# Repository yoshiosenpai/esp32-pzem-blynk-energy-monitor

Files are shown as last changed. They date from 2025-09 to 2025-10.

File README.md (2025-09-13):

# ESP32 + PZEM-004T v3.0 Energy Monitor with Blynk

Monitor **Voltage, Current, and Power** from a **PZEM-004T v3.0** and control **two AC bulbs** via relays, with live dashboards in **Blynk (Web & Mobile)**.

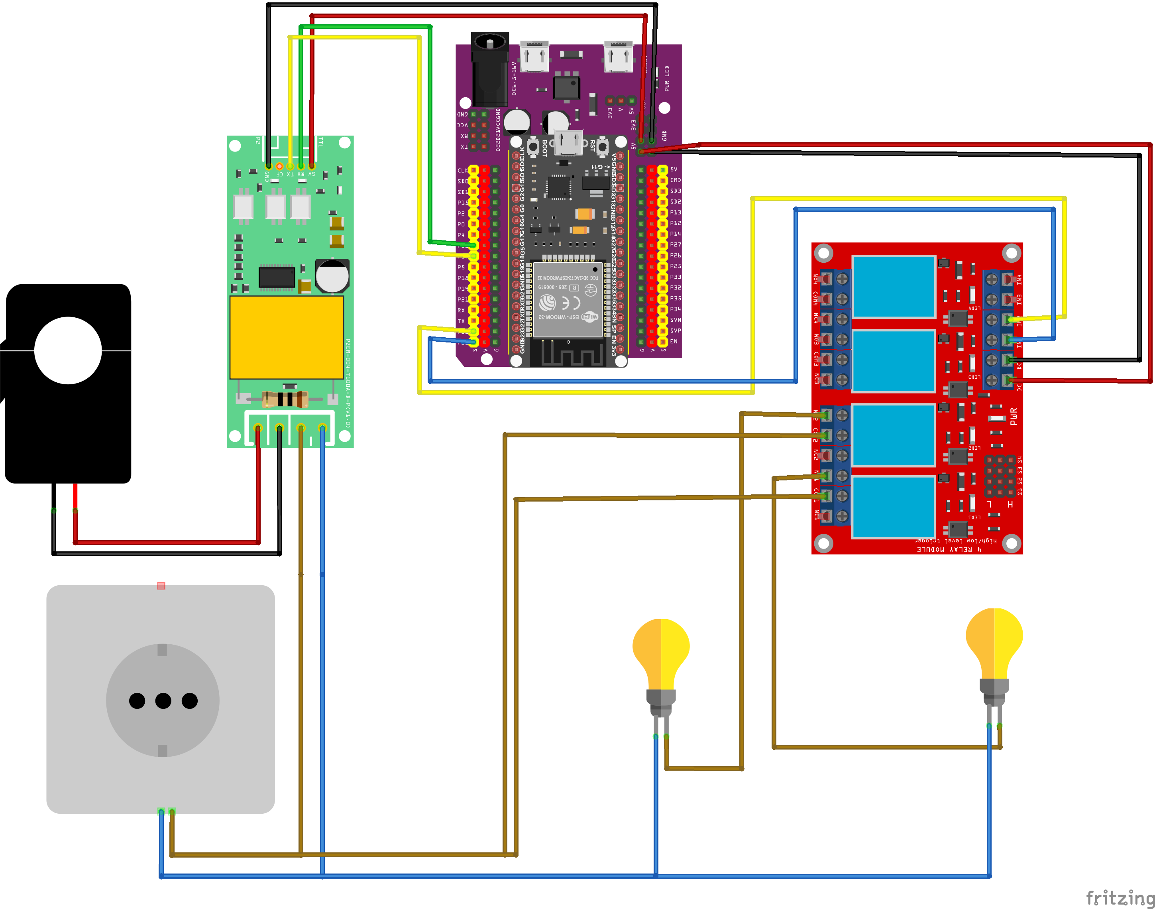
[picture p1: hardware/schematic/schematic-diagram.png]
Wiring Overview


---

## ✨ Features

* ESP32 + PZEM-004T v3.0 → real-time V/I/P/E readings
* Sends data to **Blynk Cloud** (Web & App dashboards)
* Control up to **2 relays** (bulbs, small appliances) from anywhere
* Safe wiring with CT clamp for current sensing
* Beginner-friendly: Arduino IDE only (no PlatformIO needed)

---

## 🛠 Hardware

* ESP32 Dev Board
* PZEM-004T v3.0 (with CT clamp)
* 2-Channel relay module (5V, active-LOW)
* 2 × AC bulbs + holders
* 3-pin fused plug (3A) + wiring accessories

---

## 🚀 Quickstart

1. Install **Arduino IDE** + **ESP32 board support**
2. Install libraries: `Blynk`, `PZEM004Tv30`
3. Clone this repo:

   ```bash
   git clone https://github.com/yoshiosenpai/esp32-pzem-blynk-energy-monitor.git
   ```
4. Copy `firmware/esp32_pzem_blynk/config.example.h` → `config.h` and add WiFi + Blynk token
5. Open `esp32_pzem_blynk.ino` → Select **ESP32 Dev Module** → Upload
6. Wire according to [docs/wiring-table.md](docs/wiring-table.md)
7. Open Serial Monitor → readings every \~2s
8. Open **Blynk Dashboard** → Voltage, Current, Power, Energy live + Relay switches

---

## ⚠️ Safety

This project involves **230 VAC mains**.

* Always use a **3 A fused plug**
* Keep wiring insulated and inside an enclosure
* Test with **low-wattage LED bulbs first**
* Not for heavy appliance loads

---

## 📂 Docs

* [Quickstart](docs/quickstart.md)
* [Wiring Table](docs/wiring-table.md)
* [Blynk Setup](docs/blynk-setup.md)

---

## 📜 License

MIT License – see [LICENSE](LICENSE).

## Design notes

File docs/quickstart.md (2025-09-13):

# Quickstart Guide

*ESP32 + PZEM-004T v3.0 + Blynk + Relay Energy Monitor*

---

## 1. Hardware

* ESP32 Dev Board (e.g. ESP32-DEVKIT V1)
* PZEM-004T v3.0 (AC energy monitor with CT clamp)
* 4-Channel relay module (5V, active-LOW)
* 2 × AC bulb + bulb holders (blue-stripe = Live, white = Neutral)
* CT clamp (red/black leads → S1/S2 on PZEM)
* 3-pin plug top with 3A fuse
* Breadboard / jumper wires / insulated enclosure

⚠️ **Warning:** This project uses 230 VAC mains. Always insulate, use a fused plug, and test with low-wattage LED bulbs first.

---

## 2. Arduino IDE Setup

1. Install [Arduino IDE](https://www.arduino.cc/en/software).
2. Install the **ESP32 board core**:

   * In IDE: `File → Preferences → Additional Board URLs`
   * Add:

     ```
     https://espressif.github.io/arduino-esp32/package_esp32_index.json
     ```
   * Then `Tools → Board → Boards Manager` → search **ESP32 by Espressif** → Install.
3. Install required libraries (`Tools → Manage Libraries`):

   * **Blynk** (by Volodymyr Shymanskyy)
   * **PZEM004Tv30** (by Jakub Mandula)

---

## 3. Clone the Repository

```bash
git clone https://github.com/yoshiosenpai/esp32-pzem-blynk-energy-monitor.git
cd esp32-pzem-blynk-energy-monitor/firmware/main.ino
```

---

## 4. Configure Firmware

1. Copy the example config:

   ```bash
   cp config.example.h config.h
   ```
2. Open `config.h` and edit:

   ```cpp
   #define BLYNK_TEMPLATE_ID   "YOUR_TEMPLATE_ID"
   #define BLYNK_TEMPLATE_NAME "YOUR_TEMPLATE_NAME"
   #define BLYNK_AUTH_TOKEN    "YOUR_BLYNK_AUTH_TOKEN"

   static char WIFI_SSID[] = "YOUR_WIFI";
   static char WIFI_PASS[] = "YOUR_PASSWORD";
   ```
3. In Arduino IDE: open `main.ino`.

---

## 5. Flash the ESP32

1. Select board: `Tools → Board → ESP32 Dev Module`.
2. Select correct COM port.
3. Click **Upload**.
4. Open Serial Monitor (115200 baud) → you should see live readings like:

   ```
   V=243.1 V | I=0.042 A | P=9.9 W |
   ```

---

## 6. Wiring Overview

* **Low voltage (ESP32 side):**

  * ESP32 5V → Relay VCC, PZEM VCC
  * ESP32 GND → Relay GND, PZEM GND
  * ESP32 GPIO16 (RX2) ← PZEM TX
  * ESP32 GPIO17 (TX2) → PZEM RX
  * ESP32 GPIO23 → Relay IN1
  * ESP32 GPIO22 → Relay IN2

* **High voltage (AC side):**

  * Plug **Live (L)** → PZEM L + Relay COM (both)
  * Relay NO Ch1 → Bulb1 blue-stripe (Live)
  * Relay NO Ch2 → Bulb2 blue-stripe (Live)
  * Plug **Neutral (N)** → PZEM N + Bulb1 & Bulb2 white (Neutral)

* **CT Clamp:**

  * Red → PZEM S1, Black → PZEM S2
  * Clamp around **one single Live wire** feeding the bulbs (NOT both L+N).

👉 Full wiring tables are in [`docs/wiring-table.md`](wiring-table.md).

---

## 7. Blynk Setup

1. In [Blynk Cloud](https://blynk.cloud): create a **Template → EnergyMonitor**.
2. Add Datastreams:

   * **V0** = Voltage (V)
   * **V1** = Current (A)
   * **V2** = Power (W)
   * **V10** = Relay 1 (Button)
   * **V11** = Relay 2 (Button)
3. Add Widgets:

   * Gauges / Value Displays for V0–V3
   * Switches for V10 & V11
4. Copy the **Template ID, Name, Auth Token** into `config.h`.

---

## 8. First Test

* Power on the ESP32 via USB.
* Power on the plug (with fuse) to supply the bulbs + PZEM.
* Open Serial Monitor → check Voltage ≈ 230–250 V.
* In Blynk dashboard → see V/I/P/E update every 2 s.
* Press Relay1 / Relay2 buttons → bulbs switch ON/OFF.

---

## 9. Troubleshooting

* **All values -1.0** → swap TX/RX, check 5V/GND.
* **Voltage OK, Current 0.000** → CT clamp on wrong wire / not tight / bulb OFF.
* **MCB trips immediately** → Neutral was put through relay; fix so only Live goes COM→NO.
* **ESP32 boot error (invalid header)** → unplug peripherals, erase & flash Blink, then reconnect.

---

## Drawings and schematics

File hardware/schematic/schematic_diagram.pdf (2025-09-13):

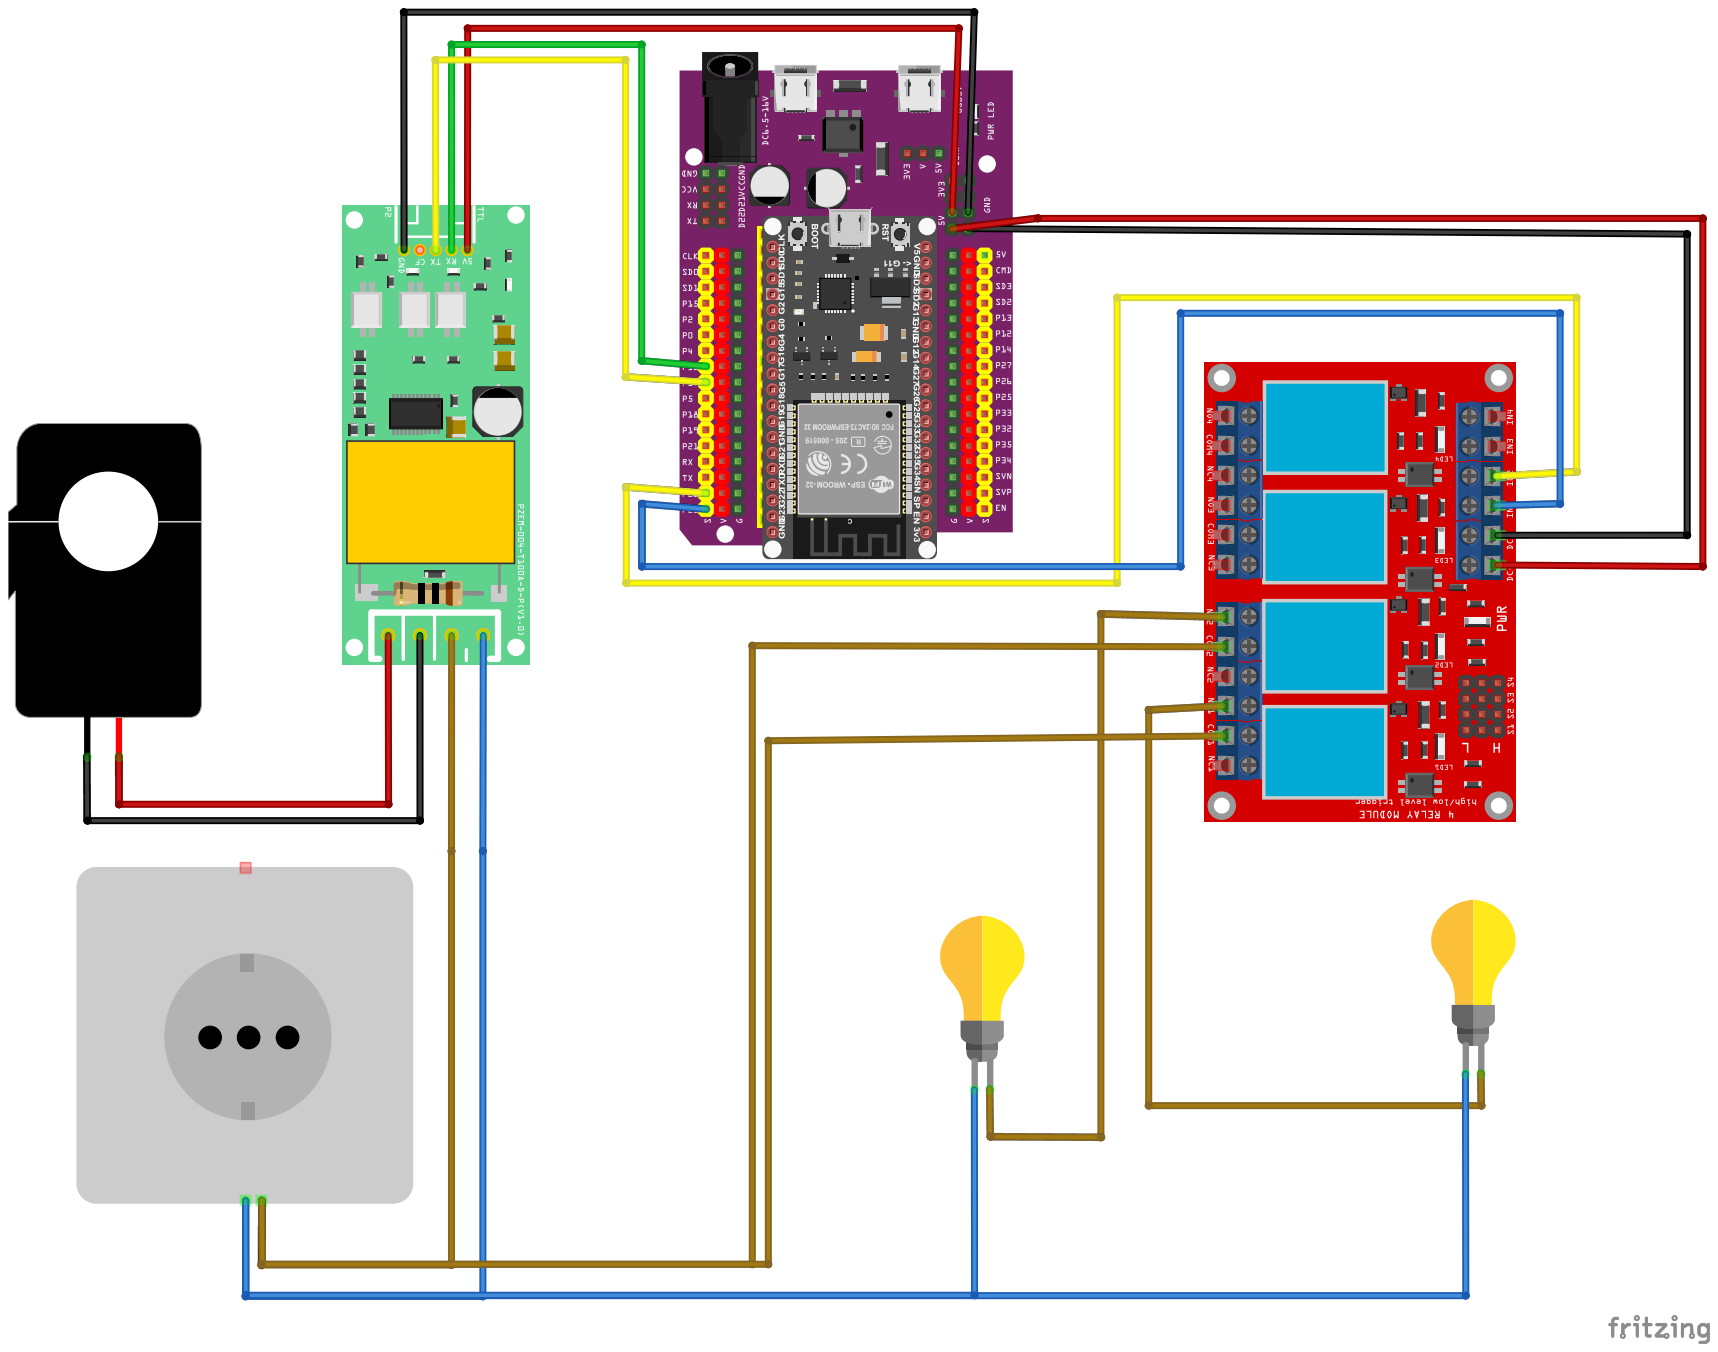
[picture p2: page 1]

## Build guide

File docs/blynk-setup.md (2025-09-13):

# Blynk Setup (Template, Datastreams, Dashboard)
> You only need to do this once per Template. After that, any device using this firmware can be provisioned in seconds.

---

## 1) Create a Blynk Template

1. Go to **[blynk.cloud](https://blynk.cloud)** → log in.
2. **Developer Zone → Templates → New Template**

   * **Template Name:** `EnergyMonitor`
   * **Hardware:** `ESP32`
   * **Connection Type:** `WiFi`
3. Click **Create**.

### Copy Template IDs

Open **Template → Device Info** and copy:

* `BLYNK_TEMPLATE_ID`
* `BLYNK_TEMPLATE_NAME`
* (We’ll get the device’s **Auth Token** after adding a device.)

Paste these into your firmware’s `config.h` later.

---

## 2) Add Datastreams (Virtual Pins)

Inside **EnergyMonitor → Datastreams → Add Datastream → Virtual Pin**
Create the following:

### Sensor values

| Name | Virtual Pin | Data Type | Units | Min | Max  | Recommended Widget |
| --- | --- | --- | ----- | --- | ---- | --- |
| Voltage | **V0** | Double | V | 0 | 260  | Value Display / Gauge |
| Current | **V1** | Double | A | 0 | 10 | Value Display / Gauge |
| Power | **V2** | Double | W | 0 | 2500 | Value Display / Gauge |
| Energy  | **V3** | Double | kWh | 0 | 9999 | Value Display |

> The firmware pushes fresh values every \~2 s.

### Relay controls

| Name | Virtual Pin | Data Type | Min | Max | Recommended Widget |
| --- | --- | --- | --- | --- | --- |
| Relay 1 | **V10** | Integer | 0 | 1 | Switch / Button |
| Relay 2 | **V11** | Integer | 0 | 1 | Switch / Button |

> 0 = OFF, 1 = ON. Most 5V relay boards are **active-LOW**; the firmware handles this for you.

*(Optional extras if you add them in code later)*

| Name | Virtual Pin | Data Type | Units | Min | Max |
| --- | --- | --- | ----- | --- | --- |
| Frequency | V4 | Double | Hz | 45  | 65  |
| PowerFactor | V5 | Double | — | 0 | 1 |

---

## 3) Create the Web Dashboard

1. In the template, open **Web Dashboard**.
2. Add widgets and map them to the datastreams:

**Recommended layout**

* **Value Display** → Voltage (V0)
* **Value Display** → Current (V1)
* **Value Display** → Power (V2)
* **Switch** → Relay 1 (V10)
* **Switch** → Relay 2 (V11)

**Widget tips**

* For Voltage/Current/Power: set **Decimals** (Voltage: 1; Current: 3; Power: 1)
* For Energy (kWh): set **Decimals: 3** (or 2)
* Title each widget clearly (e.g., “Voltage (V)”)

Click **Save** (top-right).

---

## 4) Create the Mobile Dashboard (optional)

In the **Blynk mobile app** (iOS/Android):

1. Log in with the same account.
2. Add your device (after provisioning below).
3. Add widgets and map the same pins:

   * Value Displays for **V0–V3**
   * Switches for **V10, V11**
4. Save.

---

## 5) Provision a Device (get the Auth Token)

1. Go to **My Devices → New Device → From Template**
2. Choose **EnergyMonitor**
3. Name your device (e.g., “Lab Energy Monitor”)
4. After creation, open the device → **Device Info** → copy the **Auth Token**.

Paste this **Auth Token** into your `config.h`:

```cpp
#define BLYNK_TEMPLATE_ID   "YOUR_TEMPLATE_ID"
#define BLYNK_TEMPLATE_NAME "EnergyMonitor"
#define BLYNK_AUTH_TOKEN    "PASTE_DEVICE_TOKEN_HERE"
```

Also set your Wi-Fi:

```cpp
static char WIFI_SSID[] = "YOUR_WIFI";
static char WIFI_PASS[] = "YOUR_PASSWORD";
```

Rebuild & upload the firmware.

---

## 6) Verify Data Flow

* Open **Serial Monitor (115200)** → you should see lines like:

  ```
  V=243.1 V | I=0.042 A | P=9.9 W | E=0.002 kWh
  ```
* Open your **Blynk Web Dashboard** → V0..V3 updating every \~2s.
* Use **Relay 1 / Relay 2** switches → bulbs should toggle.

If values don’t show, see Troubleshooting below.

---

## 7) Expected Ranges

* **Voltage (V0):** 200–260 V (MY mains typically \~230–245 V)
* **Current (V1):** 0.00–0.10 A for 9W LED (≈ 0.04 A typical)
* **Power (V2):** 0–200 W (≈ 7–10 W for one LED bulb)

---

## 8) Troubleshooting (Blynk side)

* **No values on dashboard, but device is online**

  * Check that each widget is mapped to the correct **Virtual Pin** (V0..V3).
  * Ensure datastream **Data Type** matches firmware (Double for sensors).
  * Confirm the device’s **Auth Token** in `config.h` matches the device in Blynk.

* **Device offline**

  * Wrong Wi-Fi SSID/PASS or token. Test with a phone hotspot.
  * Re-upload after fixing `config.h`.

* **Values frozen**

  * Check Serial Monitor for sensor errors. If firmware can’t read PZEM, it won’t push updates.
  * Make sure you **saved** the Web Dashboard after editing.

> For wiring/firmware issues (e.g., V reads OK but I=0), see `docs/troubleshooting.md`.

---

## 9) Security & Best Practices

* Don’t commit `config.h` (contains tokens/passwords). The repo ignores it via `.gitignore`.
* Use a separate **device** in Blynk for each physical ESP32.
* For public demos, regenerate Auth Tokens after.

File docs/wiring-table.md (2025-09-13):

# Wiring Table – ESP32 + PZEM-004T v3.0 + Relay + 2 Bulbs

⚠️ **Safety First**: This project involves 230 VAC. Use a fused plug (3 A), insulated terminals/enclosure, and never touch AC wiring while powered.

---

## 🔹 Low-Voltage Wiring (ESP32 → PZEM & Relay)

| From (Device) | Pin/Terminal | To (Device)  | Pin/Terminal | Notes |
| --- | --- | --- | --- | --- |
| ESP32 | 5V | PZEM-004T | VCC | Powers PZEM logic |
| ESP32 | GND | PZEM-004T | GND | Common ground |
| ESP32 (GPIO16 RX2) | RX2 | PZEM-004T | TX | Receive from PZEM |
| ESP32 (GPIO17 TX2) | TX2 | PZEM-004T | RX | Send to PZEM |
| ESP32 | 5V | Relay module | VCC | Powers relay board |
| ESP32 | GND | Relay module | GND | Common ground |
| ESP32 (GPIO23) | Digital Pin  | Relay module | IN1 | Control Relay 1 (Bulb 1) |
| ESP32 (GPIO22) | Digital Pin  | Relay module | IN2 | Control Relay 2 (Bulb 2) |

---

## 🔹 High-Voltage Wiring (AC Plug → PZEM → Relay → Bulbs)

### Common Connections

| From (Device) | Pin/Terminal | To (Device) | Pin/Terminal | Notes |
| --- | --- | --- | --- | --- |
| 3-Pin Plug | Live (L, brown) | PZEM-004T | AC-IN L | Supplies PZEM and feeds relays |
| 3-Pin Plug | Neutral (N, blue) | PZEM-004T | AC-IN N | Supplies PZEM and bulbs |
| 3-Pin Plug | Neutral (N, blue) | Bulb 1 Holder | White wire | Neutral direct to Bulb 1 |
| 3-Pin Plug | Neutral (N, blue) | Bulb 2 Holder | White wire | Neutral direct to Bulb 2 |

---

### Bulb 1 (Relay Channel 1)

| From (Device) | Pin/Terminal | To (Device) | Pin/Terminal | Notes |
| --- | --- | --- | --- | --- |
| 3-Pin Plug Live | — | Relay Ch1 | COM | Live input |
| Relay Ch1 | NO | Bulb 1 Holder | Blue-stripe (Live) | Switched Live to Bulb 1 |

---

### Bulb 2 (Relay Channel 2)

| From (Device) | Pin/Terminal | To (Device) | Pin/Terminal | Notes |
| --- | --- | --- | --- | --- |
| 3-Pin Plug Live | — | Relay Ch2 | COM | Live input |
| Relay Ch2 | NO | Bulb 2 Holder | Blue-stripe (Live) | Switched Live to Bulb 2 |

---

## 🔹 CT Clamp Wiring

| From (Device) | Pin/Lead | To (Device) | Pin/Terminal | Notes |
| --- | --- | --- | --- | --- |
| CT Clamp | Red lead | PZEM-004T | S1 | CT input |
| CT Clamp | Black lead | PZEM-004T | S2 | CT input |

* Clamp must be **around one single Live wire only** (e.g. the wire between Relay NO → Bulb Live).
* Do **not** clamp both Live + Neutral, or the reading will always be 0 A.
* If power shows negative, flip clamp orientation.

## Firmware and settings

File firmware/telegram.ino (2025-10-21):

/****************************************************
 * ESP32 + PZEM-004T v3.0 + Blynk (UNCHANGED UX)
 * + Telegram (group-ready): /status, /on1, /off1, /on2, /off2, /on, /off
 * + Night alerts per lamp (22:00–07:00 MYT) + "unknown load" alert
 * Notes:
 * - Set BotFather Group Privacy = OFF (recommended)
 * - TELEGRAM_CHAT_ID must match your group's negative ID exactly
 ****************************************************/

// ---- Blynk (unchanged) ----
#define BLYNK_TEMPLATE_ID   "BLYNK TEMPLATE ID"
#define BLYNK_TEMPLATE_NAME "BLYNK TEMPLATE NAME"
#define BLYNK_AUTH_TOKEN    "BLYNK TOKEN"

#include <Arduino.h>
#include <WiFi.h>
#include <WiFiClientSecure.h>
#include <HTTPClient.h>
#include <BlynkSimpleEsp32.h>
#include <PZEM004Tv30.h>
#include <time.h>

// ---- Wi-Fi ----
char ssid[] = "WIFI NAME";
char pass[] = "WIFI PASSWORD";

// ---- Telegram ----
// Group chat IDs are negative (e.g. "-1001234567890")
#define TELEGRAM_BOT_TOKEN "XXXXXXXX:YYYYYYYYYYYYYYYYYYYYYYYYYYYYYYY"
#define TELEGRAM_CHAT_ID   "-1001234567890"

// ---- Pins (unchanged) ----
#define RX_PIN   16   // ESP32 RX2  <- PZEM TX
#define TX_PIN   17   // ESP32 TX2  -> PZEM RX
#define RELAY1   23   // Blynk V10 (Lamp 1)
#define RELAY2   22   // Blynk V11 (Lamp 2)

const bool RELAY_ACTIVE = LOW;
const bool RELAY_IDLE   = HIGH;

// ---- Objects ----
HardwareSerial PZEMSerial(2);
PZEM004Tv30 pzem(PZEMSerial, RX_PIN, TX_PIN);
BlynkTimer timer;

// ---- Blynk handlers (unchanged) ----
BLYNK_WRITE(V10) { digitalWrite(RELAY1, param.asInt() ? RELAY_ACTIVE : RELAY_IDLE); }
BLYNK_WRITE(V11) { digitalWrite(RELAY2, param.asInt() ? RELAY_ACTIVE : RELAY_IDLE); }

// ---- Night alert settings ----
const uint8_t NIGHT_START_H = 22;   // 22:00
const uint8_t NIGHT_END_H   = 7;    // 07:00
unsigned long NIGHT_ON_MINUTES = 5; // minutes ON before alert
const unsigned long NOTIF_COOLDOWN_MS = 30UL * 60UL * 1000UL; // 30min cooldown

// Power threshold for "unknown load" (when both relays OFF)
float ON_W_THRESHOLD = 5.0; // W

// ---- State per lamp ----
struct LampState {
  uint8_t pin;
  const char* name;
  unsigned long onSinceMs = 0;
  unsigned long lastNotifMs = 0;
};
LampState lamps[2] = {
  { RELAY1, "Lamp 1" },
  { RELAY2, "Lamp 2" }
};

// Unknown load state (relays OFF but power high)
unsigned long unknownOnSinceMs = 0;
unsigned long unknownLastNotifMs = 0;

// Telegram polling
long telegramUpdateOffset = 0;

// ---- NTP Time (Asia/Kuala_Lumpur) ----
const long GMT_OFFSET_SEC = 8 * 3600;
const int  DST_OFFSET_SEC = 0;

static inline bool relayIsOn(uint8_t pin) { return digitalRead(pin) == RELAY_ACTIVE; }

bool getLocalHour(uint8_t &hourOut) {
  struct tm t;
  if (!getLocalTime(&t, 1000)) return false;
  hourOut = (uint8_t)t.tm_hour;
  return true;
}
bool inNightWindow(uint8_t hr) {
  // 22→07 wraps midnight
  if (NIGHT_START_H < NIGHT_END_H) return (hr >= NIGHT_START_H && hr < NIGHT_END_H);
  return (hr >= NIGHT_START_H || hr < NIGHT_END_H);
}

// ---------- Telegram helpers & normalization ----------
String normalizeCmd(String s) {
  s.trim();
  int sp = s.indexOf(' ');            // keep first token
  if (sp > 0) s = s.substring(0, sp);
  int at = s.indexOf('@');            // strip @botname suffix
  if (at > 0) s = s.substring(0, at);
  s.toLowerCase();
  return s;
}

bool tgSend(const String &text) {
  WiFiClientSecure client; client.setInsecure();
  HTTPClient https;
  String url = String("https://api.telegram.org/bot") + TELEGRAM_BOT_TOKEN + "/sendMessage";
  String payload = String("{\"chat_id\":\"") + TELEGRAM_CHAT_ID + "\",\"text\":\"" + text + "\"}";
  if (!https.begin(client, url)) { Serial.println("[TG] begin() failed"); return false; }
  https.addHeader("Content-Type", "application/json");
  int code = https.POST(payload);
  https.end();
  if (code < 200 || code >= 300) Serial.printf("[TG] send HTTP %d\n", code);
  return (code >= 200 && code < 300);
}

void setRelay(uint8_t pin, bool on) { digitalWrite(pin, on ? RELAY_ACTIVE : RELAY_IDLE); }

// Commands: /status, /on1, /off1, /on2, /off2, /on, /off
void tgHandleCmd(const String &raw) {
  String cmd = normalizeCmd(raw);

  if (cmd == "/status" || cmd == "/start") {
    float p = pzem.power();
    bool l1 = relayIsOn(RELAY1);
    bool l2 = relayIsOn(RELAY2);
    uint8_t hr=0; bool ok=getLocalHour(hr);
    tgSend(String("Status:\n")
      + "Lamp 1: " + (l1 ? "ON" : "OFF") + "\n"
      + "Lamp 2: " + (l2 ? "ON" : "OFF") + "\n"
      + "Line Power: " + String(p,1) + " W\n"
      + "Night window: 22:00–07:00"
      + (ok ? String("\nLocal hour: ") + hr : "\nLocal hour: (Syncing NTP)")
    );
    return;
  }

  if (cmd == "/on1")  { setRelay(RELAY1, true);  tgSend("Lamp 1 turned ON.");  return; }
  if (cmd == "/off1") { setRelay(RELAY1, false); tgSend("Lamp 1 turned OFF."); return; }
  if (cmd == "/on2")  { setRelay(RELAY2, true);  tgSend("Lamp 2 turned ON.");  return; }
  if (cmd == "/off2") { setRelay(RELAY2, false); tgSend("Lamp 2 turned OFF."); return; }

  if (cmd == "/on")   { setRelay(RELAY1, true);  setRelay(RELAY2, true);  tgSend("Both lamps ON.");  return; }
  if (cmd == "/off")  { setRelay(RELAY1, false); setRelay(RELAY2, false); tgSend("Both lamps OFF."); return; }

  // ignore others
}

void tgPoll() {
  WiFiClientSecure client; client.setInsecure();
  HTTPClient https;

  String url = String("https://api.telegram.org/bot") + TELEGRAM_BOT_TOKEN +
               "/getUpdates?timeout=10&allowed_updates=%5B%22message%22,%22edited_message%22%5D&offset=" +
               String(telegramUpdateOffset);

  if (!https.begin(client, url)) {
    Serial.println("[TG] begin() failed");
    return;
  }

  int code = https.GET();
  if (code < 200 || code >= 300) {
    Serial.printf("[TG] HTTP %d\n", code); // -11 = timeout sometimes, ignore
    https.end();
    return;
  }

  String body = https.getString();
  https.end();

  // DEBUG (peek)
  Serial.print("[TG] getUpdates OK. Body: ");
  Serial.println(body.substring(0, 300));

  int pos = body.indexOf("\"result\":[");
  if (pos < 0) return;
  pos += 10;

  while (true) {
    int uidIdx = body.indexOf("\"update_id\":", pos);
    if (uidIdx < 0) break;
    int uidStart = body.indexOf(':', uidIdx) + 1;
    int uidEnd   = body.indexOf(',', uidStart);
    long uid     = body.substring(uidStart, uidEnd).toInt();

    // prefer "message", else "edited_message"
    int msgIdx = body.indexOf("\"message\":{", uidEnd);
    int emgIdx = body.indexOf("\"edited_message\":{", uidEnd);
    int useIdx = -1; String key;

    if (msgIdx >= 0 && (emgIdx < 0 || msgIdx < emgIdx)) { useIdx = msgIdx; key = "\"message\":"; }
    else if (emgIdx >= 0) { useIdx = emgIdx; key = "\"edited_message\":"; }
    if (useIdx < 0) { pos = uidEnd; telegramUpdateOffset = uid + 1; continue; }

    // extract full JSON object for the message
    int brace = body.indexOf('{', useIdx + key.length());
    if (brace < 0) { pos = uidEnd; telegramUpdateOffset = uid + 1; continue; }
    int depth = 1, i = brace + 1;
    for (; i < (int)body.length() && depth > 0; ++i) {
      if (body[i] == '{') depth++;
      else if (body[i] == '}') depth--;
    }
    if (depth != 0) { pos = uidEnd; telegramUpdateOffset = uid + 1; continue; }
    String msgBlock = body.substring(brace, i);

    // === STRING-BASED CHAT ID (avoid overflow) ===
    String chatIdStr = "";
    int chatIdx = msgBlock.indexOf("\"chat\":");
    if (chatIdx >= 0) {
      int idKey = msgBlock.indexOf("\"id\":", chatIdx);
      if (idKey >= 0) {
        int cs = msgBlock.indexOf(':', idKey) + 1;
        int ce = msgBlock.indexOf(',', cs);
        if (ce < 0) ce = msgBlock.indexOf('}', cs);
        if (cs > 0 && ce > cs) {
          chatIdStr = msgBlock.substring(cs, ce); chatIdStr.trim();
        }
      }
    }

    // text field
    String text = "";
    int textIdx = msgBlock.indexOf("\"text\":");
    if (textIdx >= 0) {
      int q1 = msgBlock.indexOf('\"', textIdx + 7);
      int q2 = msgBlock.indexOf('\"', q1 + 1);
      if (q1 > 0 && q2 > q1) text = msgBlock.substring(q1 + 1, q2);
    }

    // advance offset for next poll
    telegramUpdateOffset = uid + 1;
    pos = i;

    // must match target group
    if (chatIdStr.length() == 0) continue;
    if (chatIdStr != String(TELEGRAM_CHAT_ID)) {
      Serial.print("[TG] Skipping chatId "); Serial.println(chatIdStr);
      continue;
    }

    if (text.length() > 0) {
      Serial.print("[TG] CMD: "); Serial.println(text);
      tgHandleCmd(text);
    }
  }
}

// ---- Core: readings + night alerts (Blynk unchanged) ----
void pushReadings() {
  static bool first = true;

  float v  = pzem.voltage();
  float i  = pzem.current();
  float p  = pzem.power();
  float e  = pzem.energy();

  if (first) { first = false; return; }
  if (isnan(v) || isnan(i) || isnan(p) || isnan(e)) {
    Serial.println("PZEM read error (check wiring).");
    return;
  }

  Serial.printf("V=%.1f V | I=%.3f A | P=%.1f W | E=%.3f kWh\n", v, i, p, e);

  // Push to Blynk (unchanged)
  Blynk.virtualWrite(V0, v);
  Blynk.virtualWrite(V1, i);
  Blynk.virtualWrite(V2, p);
  Blynk.virtualWrite(V3, e);

  // Determine night window
  uint8_t hr = 0; bool haveHr = getLocalHour(hr);
  bool night = haveHr ? inNightWindow(hr) : true; // allow alerts until NTP sync

  unsigned long now = millis();
  unsigned long targetMs = NIGHT_ON_MINUTES * 60UL * 1000UL;

  // Per-lamp night alert by RELAY state
  for (int k = 0; k < 2; ++k) {
    bool isOn = relayIsOn(lamps[k].pin);
    if (night && isOn) {
      if (lamps[k].onSinceMs == 0) lamps[k].onSinceMs = now;
      unsigned long elapsed = now - lamps[k].onSinceMs;
      if (elapsed >= targetMs) {
        bool cooldownOk = (now - lamps[k].lastNotifMs) >= NOTIF_COOLDOWN_MS;
        if (cooldownOk) {
          tgSend(String("⚠️ Night alert: ") + lamps[k].name +
                 " has been ON for " + NIGHT_ON_MINUTES + " min.");
          lamps[k].lastNotifMs = now;
        }
      }
    } else {
      lamps[k].onSinceMs = 0; // reset when off or not in night window
    }
  }

  // Unknown load alert: both relays OFF but line power high at night
  bool bothOff = !relayIsOn(RELAY1) && !relayIsOn(RELAY2);
  if (night && bothOff && p >= ON_W_THRESHOLD) {
    if (unknownOnSinceMs == 0) unknownOnSinceMs = now;
    unsigned long elapsed = now - unknownOnSinceMs;
    if (elapsed >= targetMs) {
      bool cooldownOk = (now - unknownLastNotifMs) >= NOTIF_COOLDOWN_MS;
      if (cooldownOk) {
        tgSend(String("⚠️ Night alert: Power ≈ ") + String(p,1) +
               " W while both Lamp 1 & Lamp 2 are OFF. Possible unknown load.");
        unknownLastNotifMs = now;
      }
    }
  } else {
    unknownOnSinceMs = 0;
  }
}

void setup() {
  Serial.begin(115200);

  pinMode(RELAY1, OUTPUT);
  pinMode(RELAY2, OUTPUT);
  digitalWrite(RELAY1, RELAY_IDLE);
  digitalWrite(RELAY2, RELAY_IDLE);

  // Blynk (kept as-is)
  Blynk.begin(BLYNK_AUTH_TOKEN, ssid, pass);

  // NTP time (MYT)
  configTime(GMT_OFFSET_SEC, DST_OFFSET_SEC, "pool.ntp.org", "time.nist.gov");

  // Timers
  timer.setInterval(2000, pushReadings);  // readings + alerts
  timer.setInterval(3000, tgPoll);        // Telegram commands

  tgSend("ESP32 online. Commands: /status, /on1, /off1, /on2, /off2, /on, /off");
}

void loop() {
  Blynk.run();
  timer.run();
}

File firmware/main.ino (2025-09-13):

/****************************************************
 * ESP32 + PZEM-004T v3.0 + Blynk + 2-Relay
 * Code by Solehin Rizal
 *  - Library: "PZEM004Tv30" by Jakub Mandula
 *  - UART2: RX2=GPIO16 (from PZEM TX), TX2=GPIO17 (to PZEM RX)
 *  - Blynk V0..V3 = V/I/P/E
 *  - Blynk V10 = Relay1, V11 = Relay2
 ****************************************************/

 // -------- Blynk Template / Auth --------
#define BLYNK_TEMPLATE_ID "BLYNK TEMPLATE ID"
#define BLYNK_TEMPLATE_NAME "BLYNK TEMPLATE NAME"
#define BLYNK_AUTH_TOKEN "BLYNK TOKEN"


#include <Arduino.h>
#include <WiFi.h>
#include <BlynkSimpleEsp32.h>
#include <PZEM004Tv30.h>           // v3.0 library


// -------- Wi-Fi --------
char ssid[] = "WIFI NAME";
char pass[] = "WIFI PASSWORD";

// -------- Pins --------
#define RX_PIN   16   // ESP32 RX2  <- PZEM TX
#define TX_PIN   17   // ESP32 TX2  -> PZEM RX
#define RELAY1   23   // Blynk V10
#define RELAY2   22   // Blynk V11

// Many 5V relay boards are active-LOW:
const bool RELAY_ACTIVE = LOW;
const bool RELAY_IDLE   = HIGH;

// -------- Objects --------
HardwareSerial PZEMSerial(2);      // UART2
PZEM004Tv30 pzem(PZEMSerial, RX_PIN, TX_PIN);
BlynkTimer timer;

// -- Blynk button handlers --
BLYNK_WRITE(V10) { digitalWrite(RELAY1, param.asInt() ? RELAY_ACTIVE : RELAY_IDLE); }
BLYNK_WRITE(V11) { digitalWrite(RELAY2, param.asInt() ? RELAY_ACTIVE : RELAY_IDLE); }

void pushReadings() {
  static bool first = true;

  // Read all metrics
  float v  = pzem.voltage();
  float i  = pzem.current();
  float p  = pzem.power();
  float e  = pzem.energy();

  // Discard the very first (sometimes garbage) frame
  if (first) { first = false; return; }

  // Guard NaNs
  if (isnan(v) || isnan(i) || isnan(p) || isnan(e)) {
    Serial.println("PZEM read error (check AC L/N, CT S1/S2, and TX/RX).");
    return;
  }

  // Print to Serial
  Serial.printf("V=%.1f V | I=%.3f A | P=%.1f W | E=%.3f kWh\n", v, i, p, e);

  // Push to Blynk
  Blynk.virtualWrite(V0, v);
  Blynk.virtualWrite(V1, i);
  Blynk.virtualWrite(V2, p);
  Blynk.virtualWrite(V3, e);
}

void setup() {
  Serial.begin(115200);

  // Relays
  pinMode(RELAY1, OUTPUT);
  pinMode(RELAY2, OUTPUT);
  digitalWrite(RELAY1, RELAY_IDLE);
  digitalWrite(RELAY2, RELAY_IDLE);

  // Start Blynk (handles Wi-Fi too)
  Blynk.begin(BLYNK_AUTH_TOKEN, ssid, pass);

  // Push readings every 2 seconds
  timer.setInterval(2000, pushReadings);
}

void loop() {
  Blynk.run();
  timer.run();
}
